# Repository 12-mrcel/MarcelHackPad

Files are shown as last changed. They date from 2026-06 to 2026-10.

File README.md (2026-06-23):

# MarcelHackPad
This is the repository for my HackPad Project, which is aptly named "Marcel Hack Pad"
It is a useful hackpad with a rotary encoder, allowing for some extra buttons and functionality when working on my computer.

Screenshot 2026-06-23 at 11 19 56 AM

Screenshot 2026-06-23 at 12 59 50 PM

The design is inspired by the Apollo mission control desks at NASA, I have used several images as inspiration and reference for design choices. This includes: 

1. The color palette (cream and turqouise)
1. The keycap colors 
1. The triangular name plate _"Flight Director"_ (inspired by a real photo!)
1. The NASA logo on a panel on the side

Z3C75315-scaled
(this is one of the inspirations!)

See it the project here On KiCanvas: 



## Features of the Project:

1. **Six** customizable key switches
2. A Rotary Encoder Switch
3. An opening for a USB-C cable to plug into the microcontroller

### How it works:

I used a Matrix style connection for the key switches, this was because I used 6 or more individual keys and had never designed a matrix-system before. Additionally, the Rotary Encoder Switch is plugged into the microcontroller directly, seperately to the matrix. Next, for the position of the keys and the board, I used the guide provided by HackClub on SandWhich mount keyboards. Finally, I used QMK through HomeBrew to create the firmware of the Keys, which was slightly challenging.

### Acknowledgements:

I used the 3D models provided from these links:

[Key Switches (Cherry MX)](https://github.com/hineybush/CherryMX)

[Rotary Encoder EC11](https://grabcad.com/library/rotary-encoder-17)

[General Resources and Links](https://hackpad.hackclub.com/resources)

Also, I used the HackPad manual:

[HackPad Manual Link](https://hackpad.hackclub.com/)

Finally, I must give credit to two Hackers who provided me with some inspiration and _very_ useful github repos!

[BajajPad by MrKillerShaunBa](https://github.com/MrKillerShaunBa/BajajPad/tree/main)

[HackPad by Ayushj-18](https://github.com/ayushj-18/hackpad/tree/main)

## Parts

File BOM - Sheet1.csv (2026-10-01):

Bill of Materials:
1x XIAO RP2040
6x Cherry MX Switches
1x EC11E Rotary Encoder
6x white blank DSA keycaps
6x through-hole 1N4148 Diodes
4x M3x16mm screws

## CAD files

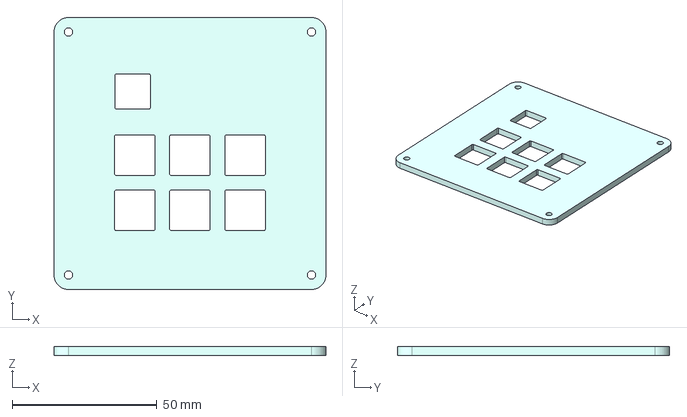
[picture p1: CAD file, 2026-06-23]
Production/MarPadTop.step
94.0 x 94.0 x 3.00 mm

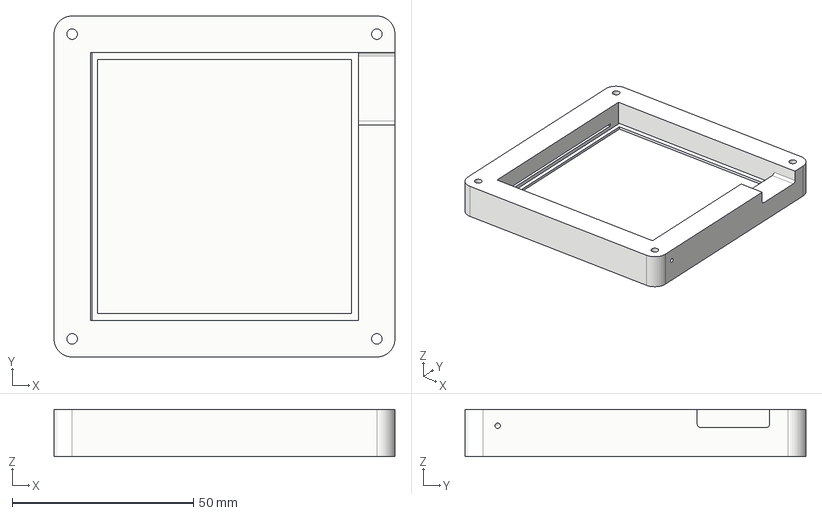
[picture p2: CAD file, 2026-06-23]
Production/MarPadBottom.step
94.0 x 94.0 x 13.0 mm

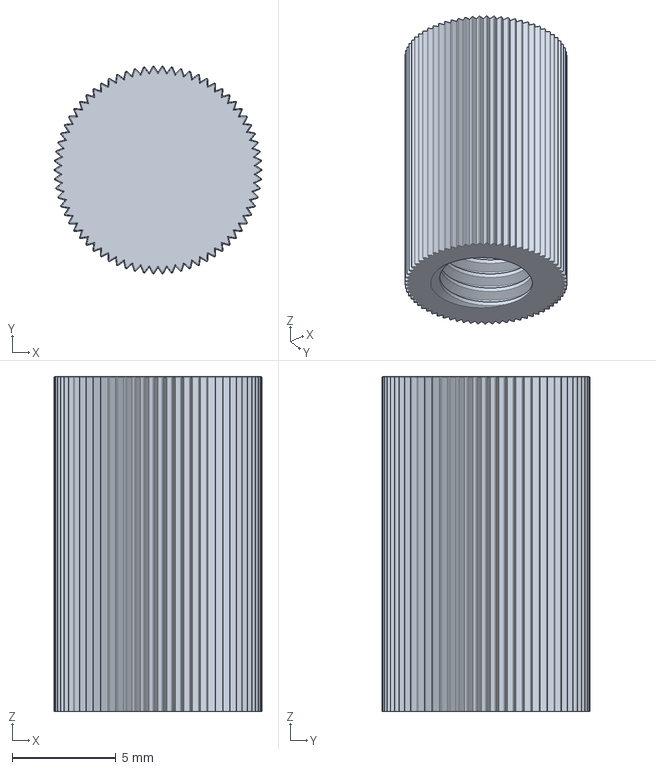
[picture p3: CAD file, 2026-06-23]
Production/MarPadRESCap.step
10.00 x 9.99 x 16.1 mm

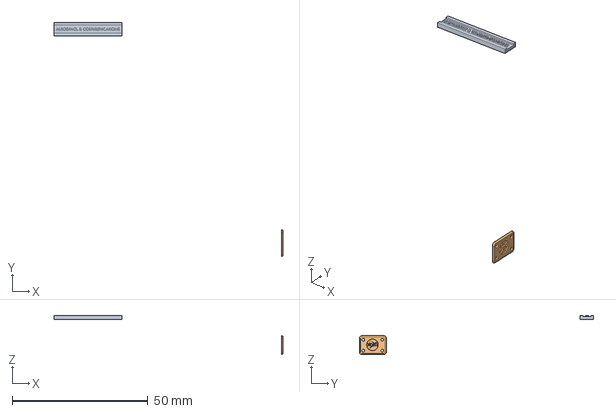
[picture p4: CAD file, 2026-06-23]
Production/MarPadAccessories.step
84.5 x 86.5 x 14.5 mm

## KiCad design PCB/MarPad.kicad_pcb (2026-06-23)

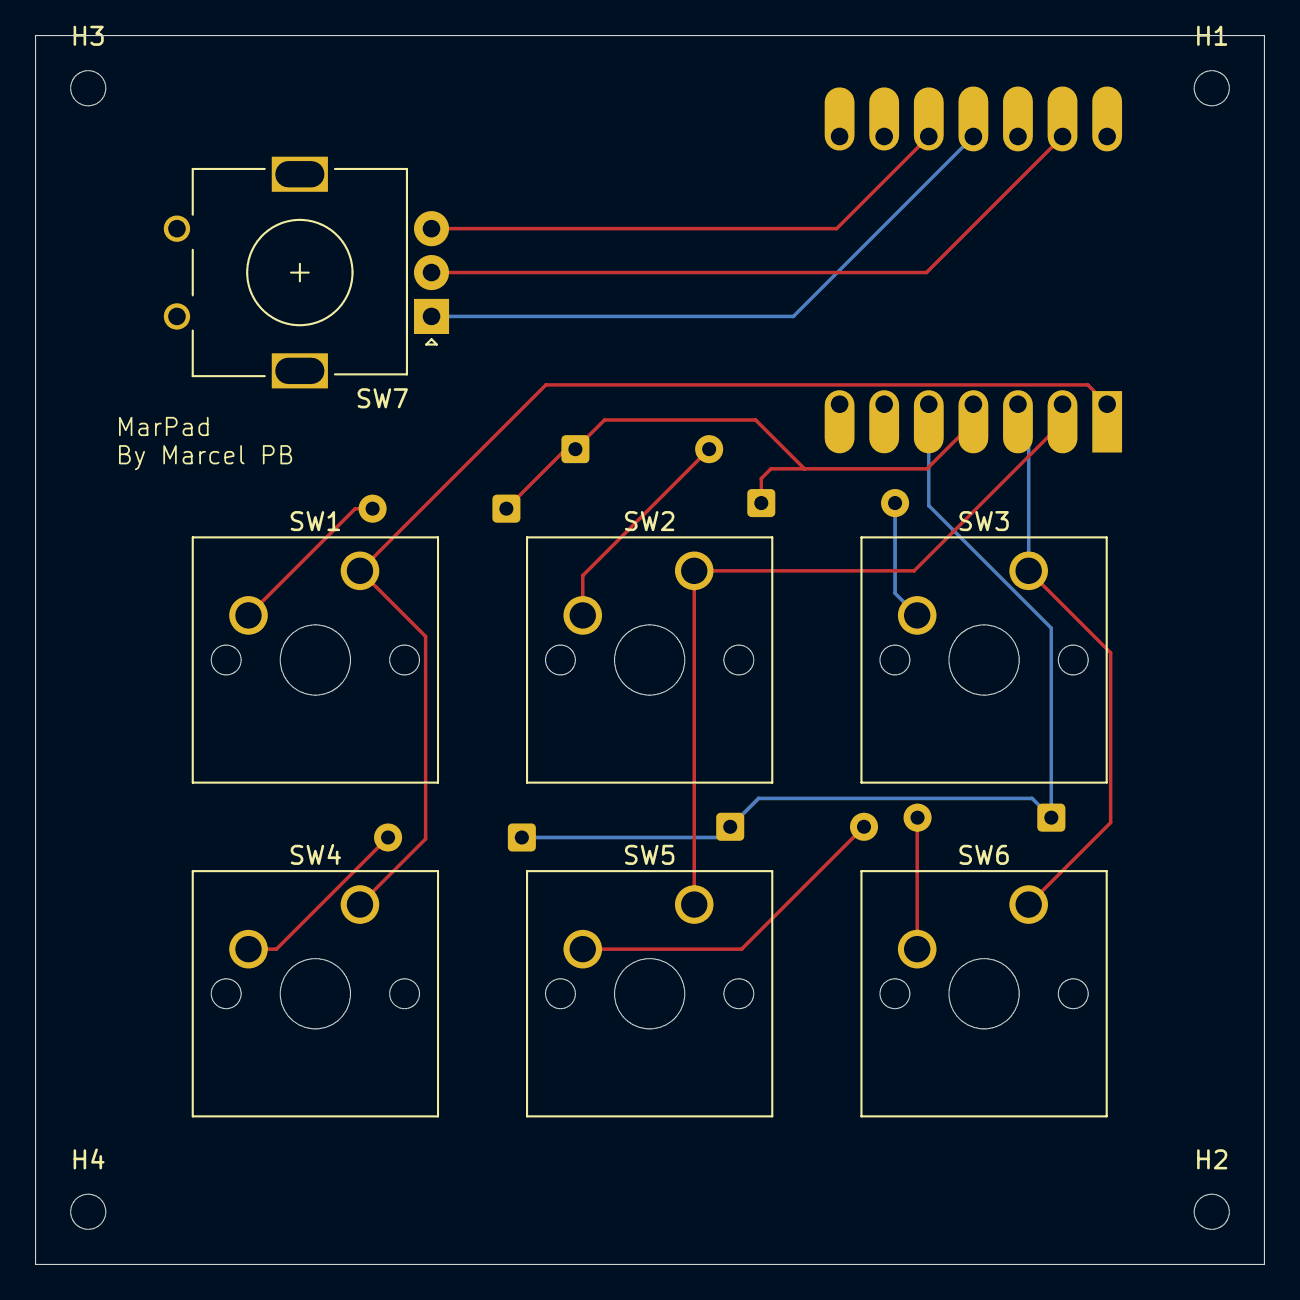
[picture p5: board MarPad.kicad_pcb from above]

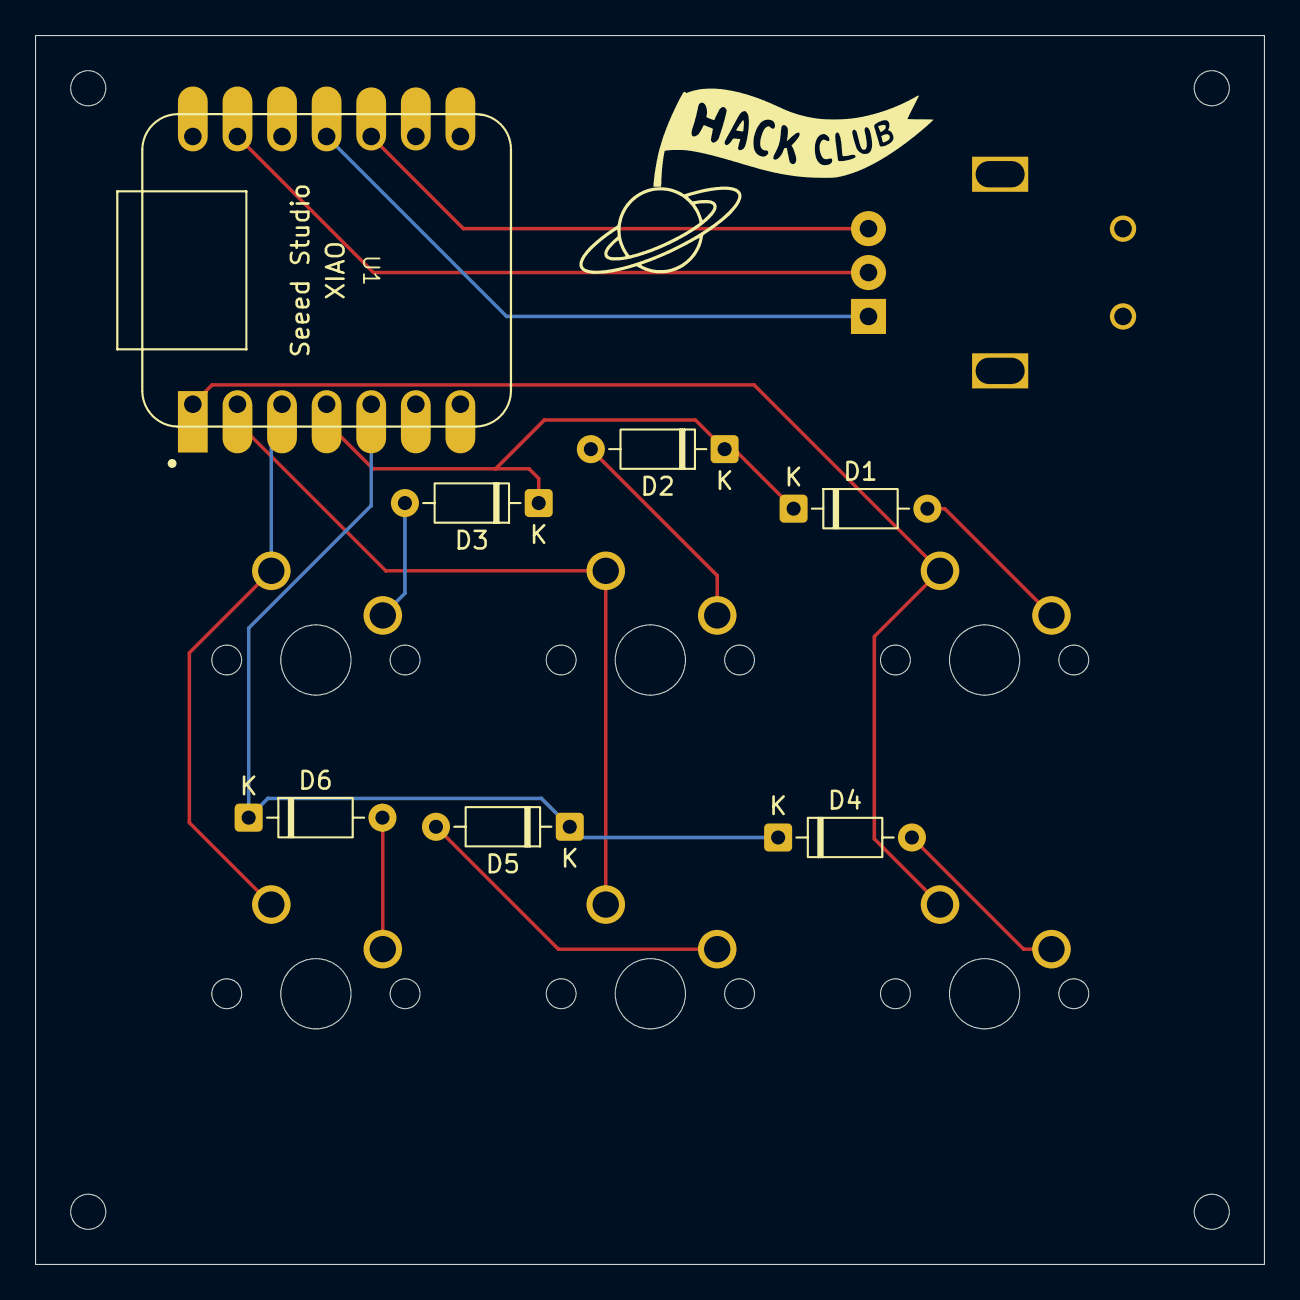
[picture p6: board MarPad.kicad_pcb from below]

Board: 2 copper layers, 70.0 x 70.0 mm, 18 parts (7 on the bottom side), 14 nets.

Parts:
D1, D2, D3, D4, D5, D6: 1N4148; D_DO-35_SOD27_P7.62mm_Horizontal
H1, H2, H3, H4: MountingHole; MountingHole_2mm
SW1, SW2, SW3, SW4, SW5, SW6: SW_Push; SW_Cherry_MX_1.00u_PCB
SW7: RotaryEncoder_Switch; RotaryEncoder_Alps_EC11E_Vertical_H20mm
U1: MOUDLE-SEEEDUINO-XIAO; XIAO-Generic-Hybrid-14P-2.54-21X17.8MM

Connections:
Col 0: SW1.1, SW4.1, U1.1 (PA02_A0_D0)
Col 1: SW2.1, SW5.1, U1.2 (PA4_A1_D1)
Col 2: SW3.1, SW6.1, U1.3 (PA10_A2_D2)
GND: SW7.C, U1.13 (GND)
unnamed: D1.2 (A), SW1.2
unnamed: D2.2 (A), SW2.2
unnamed: D3.2 (A), SW3.2
unnamed: D4.2 (A), SW4.2
unnamed: D5.2 (A), SW5.2
unnamed: D6.2 (A), SW6.2
RES A: SW7.A, U1.11 (PA6_A10_D10_MOSI)
RES B: SW7.B, U1.10 (PA5_A9_D9_MISO)
Row 0: D1.1 (K), D2.1 (K), D3.1 (K), U1.4 (PA11_A3_D3)
Row 1: D4.1 (K), D5.1 (K), D6.1 (K), U1.5 (PA8_A4_D4_SDA)

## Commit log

2026-06-23 Adding all the files for my Repo
    [MarPad.kicad_pcb, MarPad.kicad_sch]
2026-06-23 Added PCB files
    [MarPad.kicad_pcb, MarPad.kicad_sch]
2026-06-23 Production files
    [MarPadAccessories.step, MarPadBottom.step, MarPadRESCap.step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]
